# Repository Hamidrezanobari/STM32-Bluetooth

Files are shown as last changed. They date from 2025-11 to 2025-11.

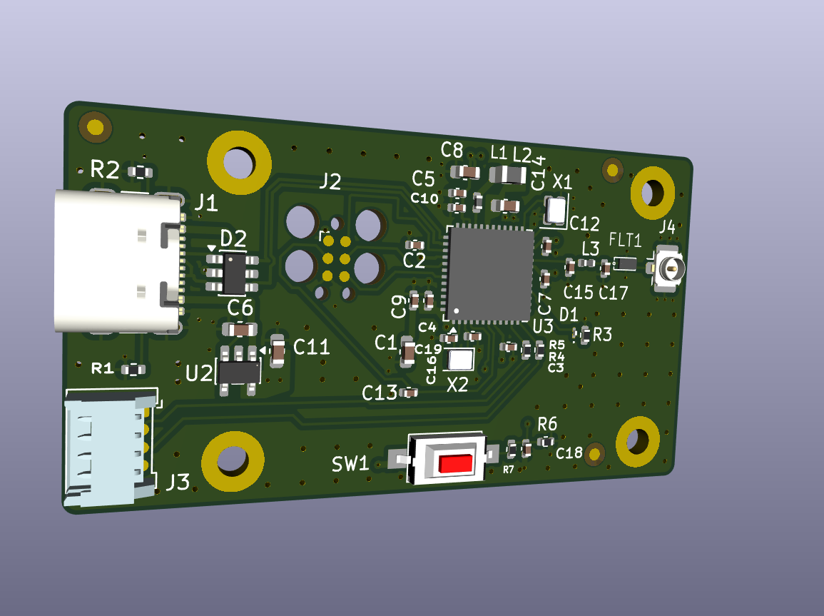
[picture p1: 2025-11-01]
3D Image.png

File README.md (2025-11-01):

# STM32 Bluetooth Development Board (stm32withBluetooth)

**A compact STM32WB55-based development board with USB-C, designed for BLE-enabled embedded projects.**

---

## At-a-glance
- **Main MCU:** STM32WB55CEU6 (Cortex-M4 + BLE radio). (Ref: `U3`)
- **Power:** MIC5365-3.3YD5 linear regulators (3.3V). (Refs: `U`, `U2`)
- **Clocking:** 32 MHz crystal + 32.768 kHz RTC crystal
- **Connectivity:** USB Type-C connector (power / USB2.0)
- **Debugging:** SWD Tag-Connect footprint (TC2030)
- **Peripherals:** LEDs, push-button, mounting holes, fiducials
- **Special footprints:** Bluetooth-specific footprint / antenna footprint present (`bluetoothLib` folder)
- **Outputs included:** KiCad schematic (`*.kicad_sch`), PCB (`*.kicad_pcb`), footprints (`*.pretty`), 3D STEP models, and Gerbers under `Manufacturing/`.

---

## Contents of this repository
```
/stm32withBlueto0th.kicad_sch        # KiCad schematic
/stm32withBlueto0th.kicad_pcb        # KiCad PCB file
/*.pretty/                           # custom footprints (including bluetooth footprint)
3D/                                  # STEP models (STM32WB, crystals, etc.)
Manufacturing/                       # Gerber files for PCB manufacturing
/stm32withBlueto0th-backups/         # backup ZIPs and prior versions
README.md (this file)
```

---

## Key components (auto-detected / inferred)
> Below are the main parts identified in the schematic. Reference names follow the schematic where available.

- **U3** — `STM32WB55CEU6` (main MCU with integrated BLE radio)  
- **U**, **U2** — `MIC5365-3.3YD5` (3.3V LDO regulators)  
- **J1** — `USB_C_Receptacle_USB2.0_16P` (USB-C connector footprint)  
- **J2** — `Conn_ARM_SWD_TagConnect_TC2030` (SWD / Tag-Connect debug header)  
- **X1** — `32 MHz crystal` (main oscillator for MCU)  
- **Y? / FLT** — `32.768 kHz` (RTC crystal footprint present; 3D models show `NX2012SA-32.768K`)  
- **DLF162500LT-5028A1** — footprint present in `bluetoothLib` (likely antenna or related footprint)  
- Passive components: decoupling caps (100nF etc.), bulk caps (4.7uF), resistors (5k1, 220R, ...), inductors (L - power/filter), LEDs, push-button (SW)  
- Mechanical: mounting holes, fiducials, board outline and edge cuts (Gerbers included)

---

## Board functions & intended use
This board appears designed as a small STM32WB55 development / application board for BLE-enabled projects that require:
- USB (power / potential USB data),
- programming via SWD Tag-Connect or USB DFU (if firmware supports it),
- RTC support (32.768 kHz crystal),
- on-board antenna footprint / matching network for BLE,
- stable 3.3V supply from onboard LDO(s).

Use-cases: BLE peripherals, sensor nodes, gateway prototypes (with additional modules), low-power development.

---

## How to build and flash (recommended workflow)

### 1. Open the project
- Use **KiCad (2024/2025)** — the schematic/pcb files indicate KiCad 2024/2025 file formats.  
- Open `stm32withBlueto0th.kicad_sch` in Eeschema and `stm32withBlueto0th.kicad_pcb` in Pcbnew.

### 2. Generate BOM & Gerbers
- BOM (CSV): Eeschema → Generate BOM (or run a script to parse `*.kicad_sch`).  
- Gerbers already provided under `Manufacturing/` if you want to order boards.

### 3. Programming options
- **SWD Tag-Connect**: Use an ST-LINK (or any SWD programmer) with a Tag-Connect cable connected to the TC2030 footprint (`J2`). If no TC cable, use small wires to the labelled SWD pads.  
- **USB DFU (optional)**: If firmware implements USB DFU (and USB lines are connected to MCU's USB pins & VBUS detection), you can flash via DFU over USB-C. Verify schematic that MCU USB D+/D- are connected correctly and that VBUS is present on the USB connector.  
- **Toolchain:** Use **STM32CubeIDE** or GCC arm toolchain + STM32CubeWB middleware (for wireless stacks). STM32CubeWB package contains BLE stack examples for STM32WB series.

### 4. Flashing steps (example using ST-LINK + STM32CubeIDE)
1. Connect ST-LINK to the Tag-Connect footprint (or SWD wires).  
2. Open or create the firmware project in STM32CubeIDE (select MCU: STM32WB55CEUx).  
3. Build and Run → Debug to program flash.

---

## Notes, observations & suggestions (from analysis)
1. **No CAN:** If your aim is automotive / CAN interfacing, add an external CAN transceiver (e.g. SN65HVD230) and a CAN connector (DB9/OBD or screw terminal) plus 120Ω termination. STM32WB has CAN only on some MCU families — double-check pin availability or switch to an STM32 with bxCAN if heavy CAN work is planned (e.g., STM32F1/F4/F7 families or some F4/F7 parts with CAN).  
2. **Antenna / RF:** Project contains Bluetooth footprint and 3D part models. Verify antenna keepout, matching network, and ground plane per STM32WB datasheet and antenna vendor recommendations before mass-production. RF layout rules matter!  
3. **Power:** Two MIC5365 LDOs appear — ensure proper decoupling and thermal consideration. If you need low-power sleep modes for BLE, consider using low-Iq regulator or switch to buck converter for higher efficiency depending on current draw.  
4. **USB:** If you plan USB device functionality, ensure ESD and VBUS protection components are present (TVS, VBUS resistors). I saw VBUS nets in schematic; double-check for differential pair routing and correct USB pull-up/pull-down resistors if needed.  
5. **Test points & silkscreen:** Add clear test points for SWD, VCC, GND, and important signals for easier debugging/manufacturing testing.

---

## Next steps I can do for you (choose one or more)
- [ ] Generate a **detailed BOM (CSV)** automatically from the schematic (refs, values, footprints).  
- [ ] Extract a **component list with footprints** and produce a printable BOM + place file.  
- [ ] Produce a **hardware overview section** with annotated PCB screenshots (I can create PNGs of the PCB from the KiCad files if you want).  
- [ ] Add a **“How to flash”** step-by-step with exact pinouts for Tag-Connect and example STM32CubeIDE project skeleton (I can also provide a sample `main.c`).  
- [ ] Convert README to **dual-language (English + Persian)**.

---

## License
Add your preferred license file to the repo. If you want, I can add a recommended license (e.g., MIT) and include it in the README.

---

## Author
Your name (please replace): **_Your Name Here_**  
Auto-generated analysis performed by script on included KiCad project files (`stm32withBlueto0th.zip`).

---

### Quick disclaimer
This README and the component identification were autogenerated by parsing the KiCad schematic and PCB files in this zip. Some values/footprints (e.g., custom footprints, exact antenna tuning components) might require manual verification. If you want, I can produce a fully verified BOM by cross-checking every symbol in the schematic and matching footprints—tell me and I’ll generate it next.

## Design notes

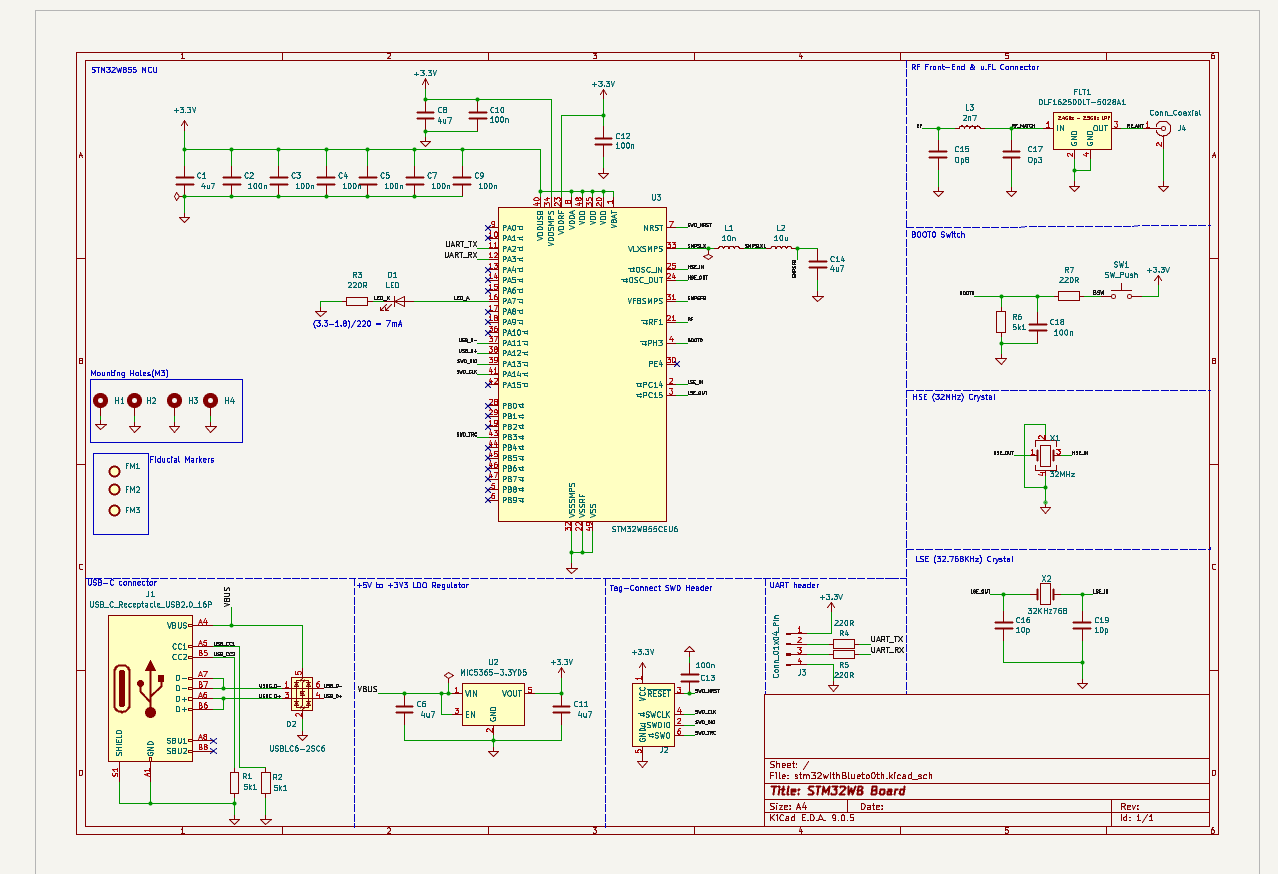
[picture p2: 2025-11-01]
photo.png

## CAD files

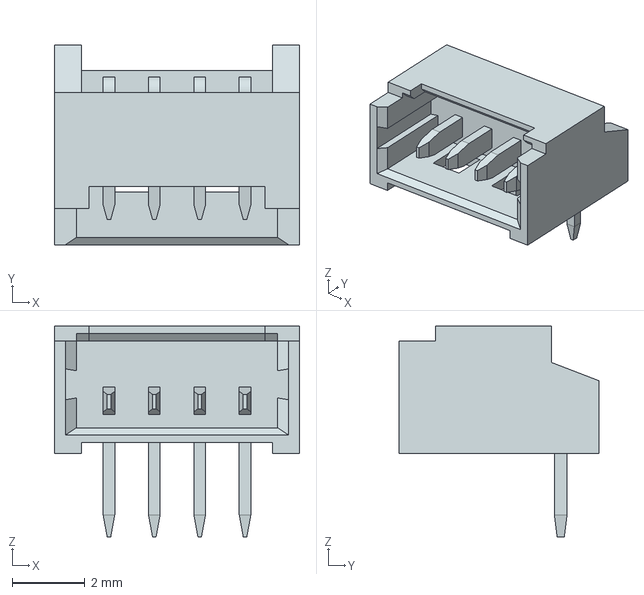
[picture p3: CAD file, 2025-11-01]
0530480410.stp
6.75 x 5.50 x 5.80 mm

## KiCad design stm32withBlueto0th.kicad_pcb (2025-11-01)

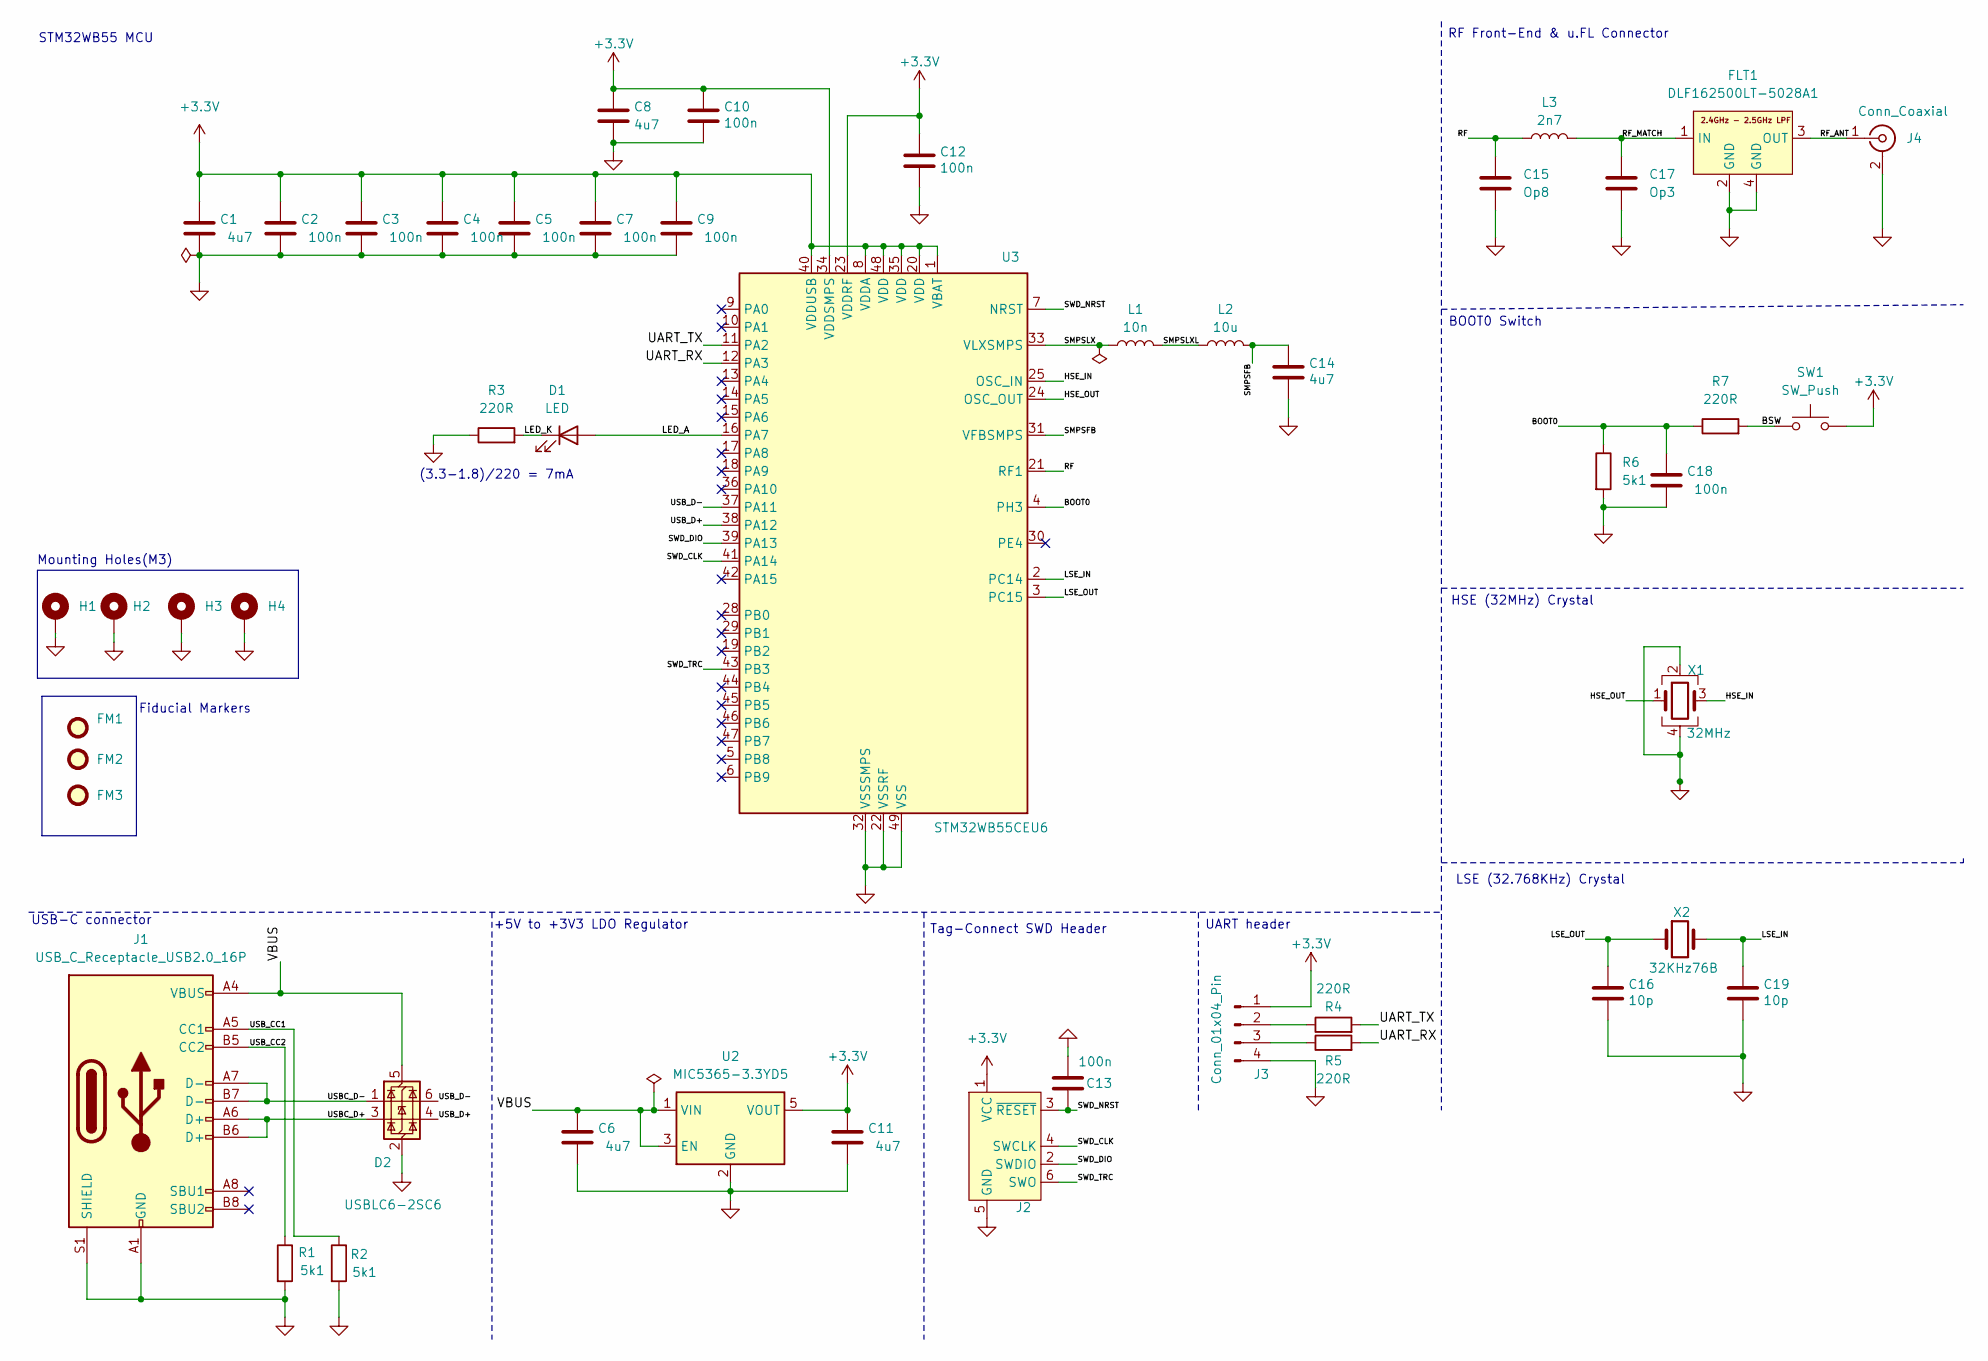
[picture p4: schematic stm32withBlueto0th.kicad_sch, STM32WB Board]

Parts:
C1, C6, C8, C11, C14: 4u7; C_0603_1608Metric; Manufacturere part numb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 0603YD475MAT2A
C2, C3, C4, C5, C7, C9, C10, C12, C13, C18: 100n; C_0402_1005Metric; Manufacturere part numb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 04023C104KAT2A
C15: Op8; C_0402_1005Metric; Manufacturere part numb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 GRM1555C1HR80BA01D
C16, C19: 10p; C_0402_1005Metric; Manufacturere part numb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 04025A100JAT4A
C17: Op3; C_0402_1005Metric; Manufacturere part numb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 GRM1555C1HR30WA01D
D1: LED; LED_01005_0402Metric; Manufacturere part numb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 150040RS73240
D2: USBLC6-2SC6; SOT-23-6; Manufacturere part numb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 USBLC6-2SC6
FLT1: DLF162500LT-5028A1; Manufacturere part numb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 DLF162500LT-5028A1
FM1, FM2, FM3: Fiducial; Fiducial_1mm_Mask2mm
H1, H2, H3, H4: MountingHole_Pad; MountingHole_2.2mm_M2_Pad
J1: USB_C_Receptacle_USB2.0_16P; USB_C_Receptacle_GCT_USB4105-xx-A_16P_TopMnt_Horizontal; Manufacturere part numb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 USB4105-GF-A
J2: Conn_ARM_SWD_TagConnect_TC2030; Tag-Connect_TC2030-IDC-FP_2x03_P1.27mm_Vertical
J3: Conn_01x04_Pin; Molex_PicoBlade_53048-0410_1x04_P1.25mm_Horizontal; Manufacturere part numb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 53048-0410
J4: Conn_Coaxial; U.FL_Hirose_U.FL-R-SMT-1_Vertical; Manufacturere part numb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 U.FL-R-SMT(01)
L1: 10n; L_0402_1005Metric; Manufacturere part numb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 LQG15WZ10NJ02D
L2: 10u; L_0805_2012Metric; Manufacturere part numb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 LQM21FN100M70L
L3: 2n7; L_0402_1005Metric; Manufacturere part numb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 LQG15HS2N7S02
R1, R2, R6: 5k1; R_0402_1005Metric; Manufacturere part numb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 RC0603FR-075K1L
R3, R4, R5, R7: 220R; R_0402_1005Metric; Manufacturere part numb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 RC0402FR-07221RL
SW1: SW_Push; SW_SPST_CK_RS282G05A3; Manufacturere part numb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 RS282G05A3SMRT
U2: MIC5365-3.3YD5; TSOT-23-5; Manufacturere part numb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 MIC5365-3.3YD5-TR
U3: STM32WB55CEU6; QFN-48-1EP_7x7mm_P0.5mm_EP5.6x5.6mm; Manufacturere part numb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 STM32WB55CEU6
X1: 32MHz; Crystal_SMD_2016-4Pin_2.0x1.6mm; Manufacturere part numb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 NX2016SA-32M-EXS00A-CS06465
X2: 32KHz76B; Crystal_SMD_2012-2Pin_2.0x1.2mm; Manufacturere part numb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 NX2012SA-32.768K-STD-MUB-1

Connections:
+3.3V: C1.1, C2.1, C3.1, C4.1, C5.1, C7.1, C8.1, C9.1, C10.1, C11.1, C12.1, J2.1 (VCC), J3.1, SW1.2, U2.5 (VOUT), U3.1 (VBAT), U3.8 (VDDA), U3.20 (VDD), U3.23 (VDDRF), U3.34 (VDDSMPS), U3.35 (VDD), U3.40 (VDDUSB), U3.48 (VDD)
/BOOT0: C18.1, R6.1, R7.1, U3.4 (PH3)
/BSW: R7.2, SW1.1
/HSE_IN: U3.25 (OSC_IN), X1.3
/HSE_OUT: U3.24 (OSC_OUT), X1.1
/LED_A: D1.2 (A), U3.16 (PA7)
/LED_K: D1.1 (K), R3.2
/LSE_IN: C19.1, U3.2 (PC14), X2.2
/LSE_OUT: C16.1, U3.3 (PC15), X2.1
/RF: C15.1, L3.1, U3.21 (RF1)
/RF_ANT: FLT1.3 (OUT), J4.1 (In)
/RF_MATCH: C17.1, FLT1.1 (IN), L3.2
/SMPSFB: C14.1, L2.2, U3.31 (VFBSMPS)
/SMPSLX: L1.1, U3.33 (VLXSMPS)
/SMPSLXL: L1.2, L2.1
/SWD_CLK: J2.4 (SWCLK), U3.41 (PA14)
/SWD_DIO: J2.2 (SWDIO), U3.39 (PA13)
/SWD_NRST: C13.1, J2.3 (~RESET), U3.7 (NRST)
/SWD_TRC: J2.6 (SWO), U3.43 (PB3)
/UART_RX: R5.2, U3.12 (PA3)
/UART_TX: R4.2, U3.11 (PA2)
/USBC_D+: D2.3 (I/O2), J1.A6 (D+), J1.B6 (D+)
/USBC_D-: D2.1 (I/O1), J1.A7 (D-), J1.B7 (D-)
/USB_CC1: J1.A5 (CC1), R2.1
/USB_CC2: J1.B5 (CC2), R1.1
/USB_D+: D2.4 (I/O2), U3.38 (PA12)
/USB_D-: D2.6 (I/O1), U3.37 (PA11)
/VBUS: C6.1, D2.5 (VBUS), J1.A4 (VBUS), J1.A9 (VBUS), J1.B4 (VBUS), J1.B9 (VBUS), U2.1 (VIN), U2.3 (EN)
GND: C1.2, C2.2, C3.2, C4.2, C5.2, C6.2, C7.2, C8.2, C9.2, C10.2, C11.2, C12.2, C13.2, C14.2, C15.2, C16.2, C17.2, C18.2, C19.2, D2.2 (GND), FLT1.2 (GND), FLT1.4 (GND), H1.1, H2.1, H3.1, H4.1, J1.A1 (GND), J1.A12 (GND), J1.B1 (GND), J1.B12 (GND), J1.S1 (SHIELD), J2.5 (GND), J3.4, J4.2 (Ext), R1.2, R2.2, R3.1, R6.2, U2.2 (GND), U3.22 (VSSRF), U3.32 (VSSSMPS), U3.49 (VSS), X1.2, X1.4
unnamed: J3.2, R4.1
unnamed: J3.3, R5.1

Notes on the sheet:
Mounting Holes(M3)
+5V to +3V3 LDO Regulator
STM32WB55 MCU
UART header
(3.3-1.8)/220 = 7mA
RF Front-End & u.FL Connector
LSE (32.768KHz) Crystal
Tag-Connect SWD Header
USB-C connector
BOOT0 Switch
Fiducial Markers
HSE (32MHz) Crystal

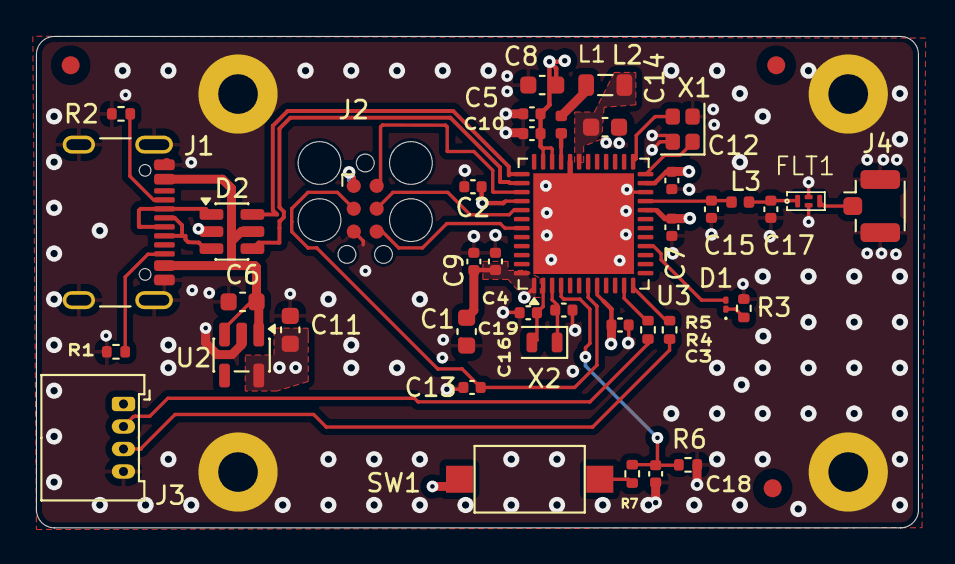
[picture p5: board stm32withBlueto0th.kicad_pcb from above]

Board: 4 copper layers, 49.0 x 27.3 mm, 48 parts (0 on the bottom side), 31 nets.
